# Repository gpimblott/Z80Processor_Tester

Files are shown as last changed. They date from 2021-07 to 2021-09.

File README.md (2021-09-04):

# Z80Processor_Tester
This is a simple tester PCB for Z80 processors.  I use it for testing processors taken from ZX81 and Spectrums that I am fixing... also to test processors that I buy online.

## Software

The software is written in MPLab X to be used on a PIC 16F690 microcontroller

## Hardware

The PCB is designed in KiCad and all the necessary files are provided to create your own version

# Versions and updates

## v01 : Hardware and Software

Initial version that cycles through the address lines by returning a NOP instructuction (all zeros) for every address.  The leds will cycle through a binary sequence until the ram refresh kicks in then it will skip about.  This is still enough to test the basic operation of the chip and has enabled me to verify several dead Z80's.

This is complete and I have had boards made at PCBWay using the .zip file in the releases tab and also included in the hardware/v01 directory.  THe PCB has a non-standard DC barrel jack footprint.  I was unable to find a component to match so I 'bodged' a normal jack.

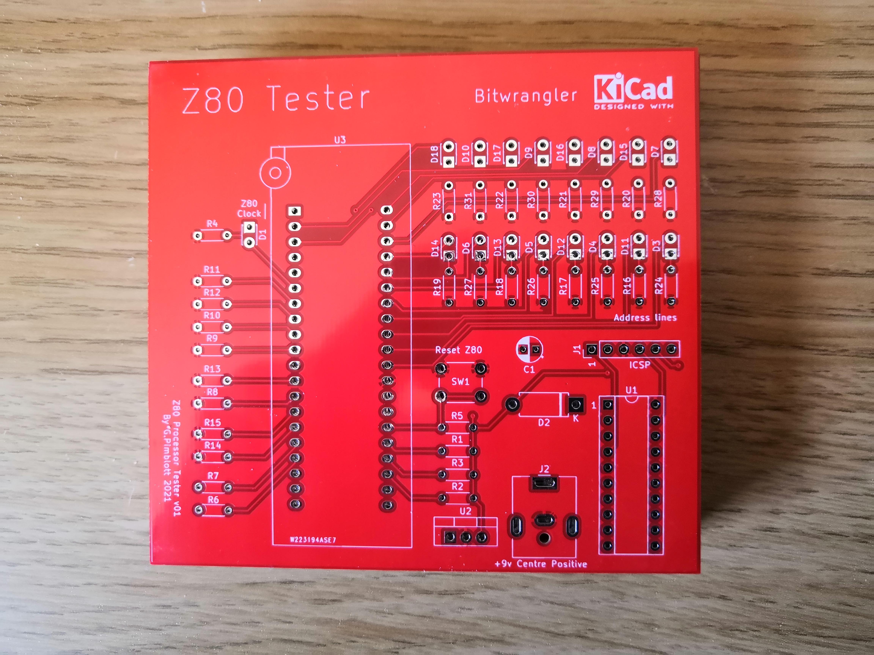
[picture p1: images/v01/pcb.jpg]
v01 PCB


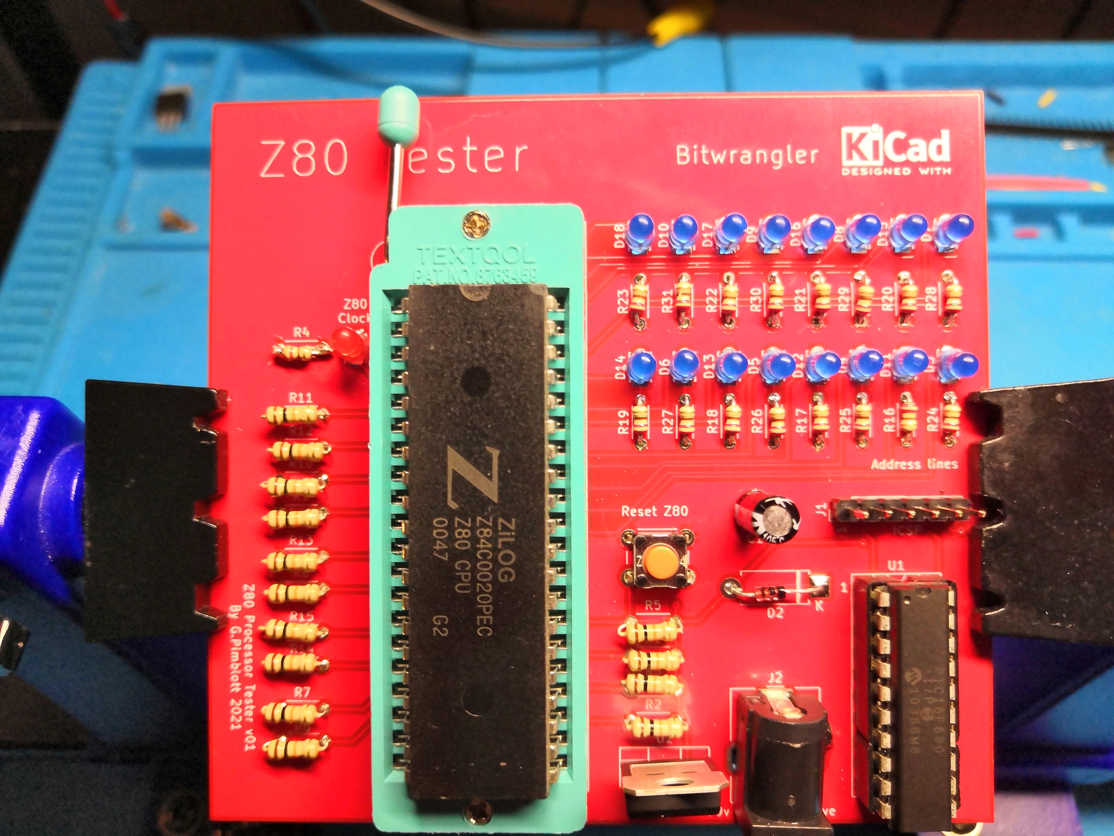
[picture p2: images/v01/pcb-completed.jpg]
v01 Completed board


## v02 : Hardware and Software - WIP

Do NOT use the hardware or software - this is WIP

This is an updated version that adds the following
* filters the DRAM refresh cycles
* Stop / Start buttons

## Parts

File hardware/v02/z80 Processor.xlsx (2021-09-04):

Component Count: | 44
Ref | Qnty | Value | Cmp name | Description
C1, | 1 | 100uf | CP | Polarized capacitor
D1, D3, D4, D5, D6, D7, D8, D9, D10, D11, D12, D13, D14, D15, D16, D17, D18, | 17 | LED | LED | Light emitting diode
D2, | 1 | 1N4148 | D_Schottky | Schottky diode
J1, | 1 | Header pins | Conn_PIC_ICSP_ICD | Microchip PIC In-Circuit Serial Programming/Debugging (ICSP/ICD) connector
J2, | 1 | Barrel_Jack | Barrel_Jack | DC Barrel Jack
R1, | 1 | 10K | R | Resistor
R4, R16, R17, R18, R19, R20, R21, R22, R23, R24, R25, R26, R27, R28, R29, R30, R31, | 17 | 150 | R | Resistor
R5, | 1 | 10k | R | Resistor
SW1, | 1 | SW_Push_Dual | SW_DPST_x2 | Single Pole Single Throw (SPST) switch, separate symbol
U1, | 1 | PIC16F690 | PIC16F690 | 4096W Flash, 256B SRAM, 256B EEPROM, DIP20
U2, | 1 | L7805 | L7805 | Positive 1.5A 35V Linear Regulator, Fixed Output 5V, TO-220/TO-263/TO-252
U3, | 1 | Z80CPU | ZIF Socket | ZIF Socket for Z80

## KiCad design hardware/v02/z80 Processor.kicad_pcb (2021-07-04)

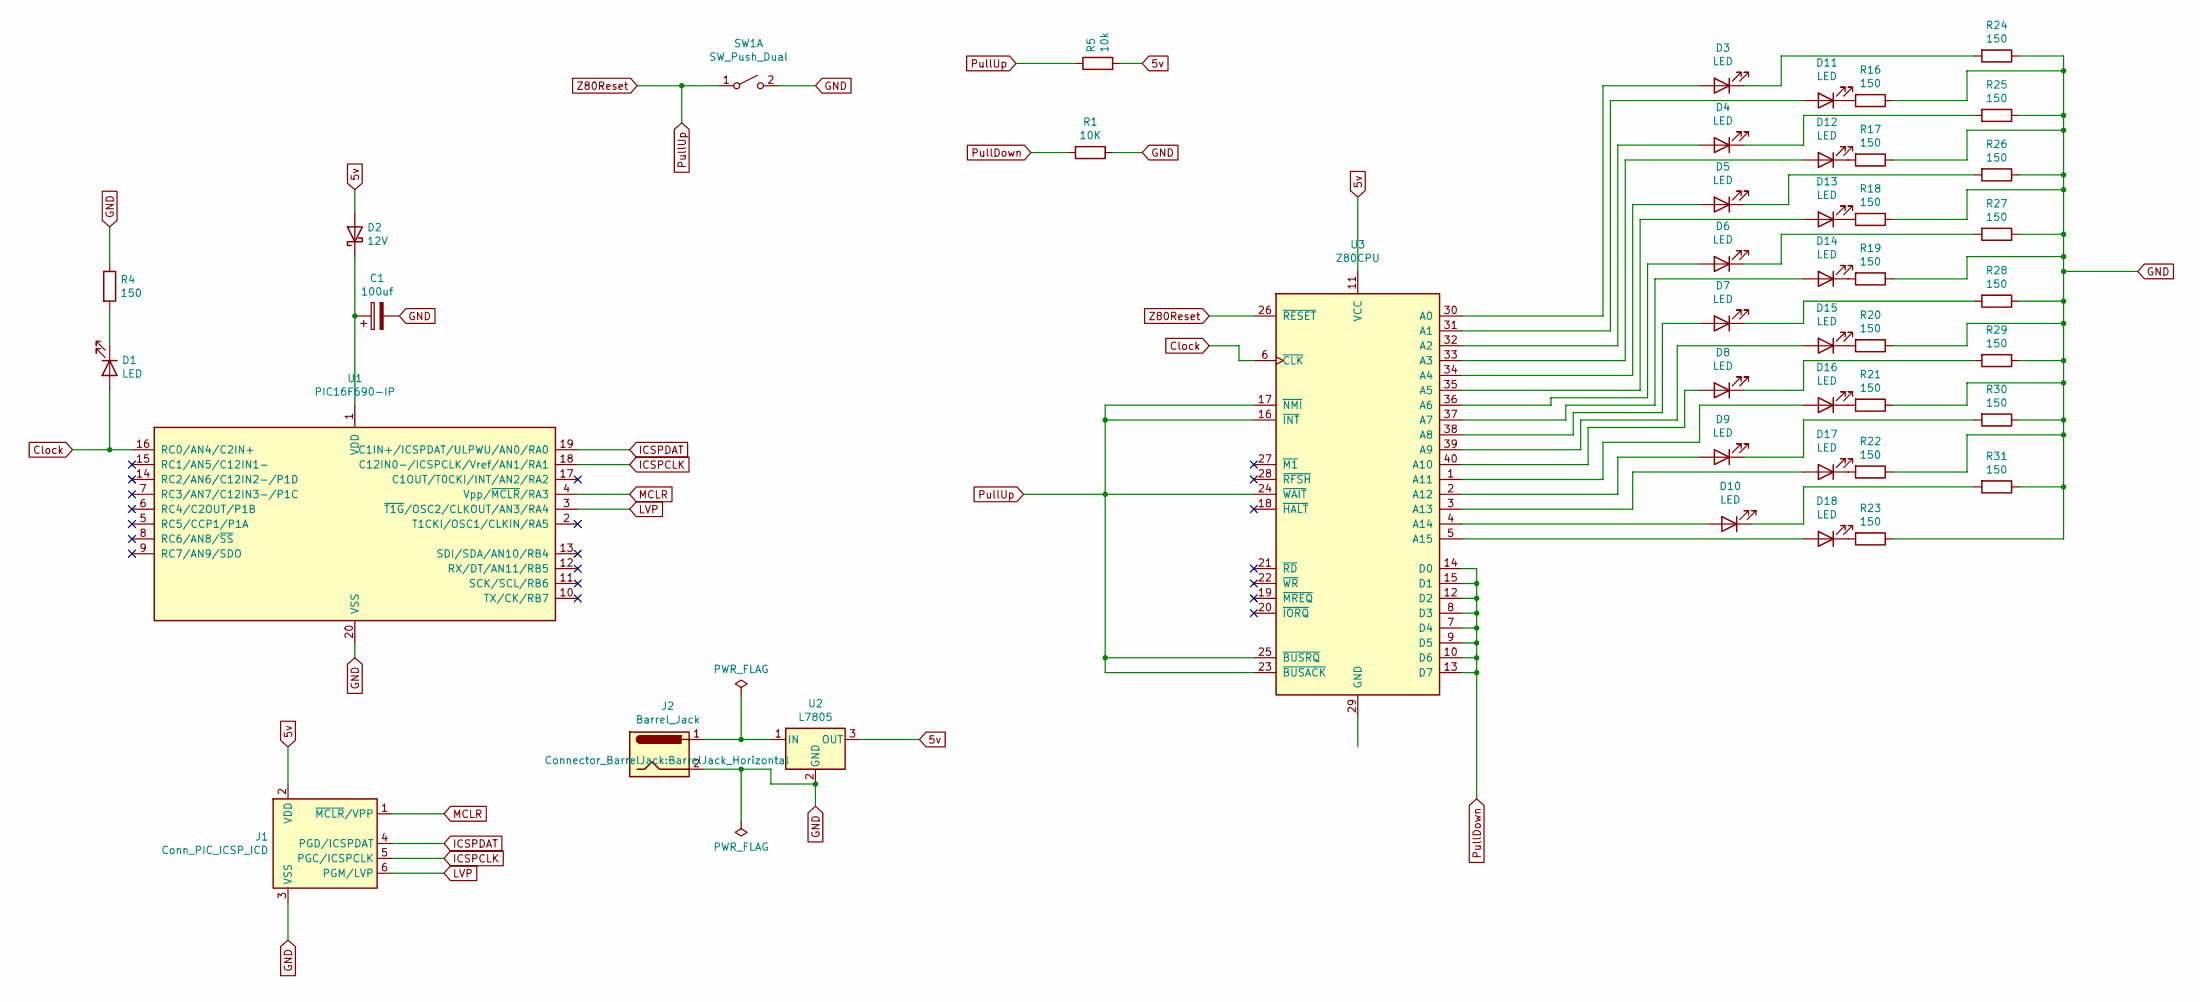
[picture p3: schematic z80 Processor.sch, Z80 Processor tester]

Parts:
C1: 100uf; CP_Radial_D4.0mm_P2.00mm
D1, D3, D4, D5, D6, D7, D8, D9, D10, D11, D12, D13, D14, D15, D16, D17, D18: LED; LED_D1.8mm_W3.3mm_H2.4mm
D2: 12V; D_DO-15_P10.16mm_Horizontal
J1: Conn_PIC_ICSP_ICD; PinHeader_1x06_P2.54mm_Vertical
J2: Barrel_Jack; BarrelJack_Horizontal
R1: 10K; R_Axial_DIN0204_L3.6mm_D1.6mm_P5.08mm_Horizontal
R4, R16, R17, R18, R19, R20, R21, R22, R23, R24, R25, R26, R27, R28, R29, R30, R31: 150; R_Axial_DIN0204_L3.6mm_D1.6mm_P5.08mm_Horizontal
R5: 10k; R_Axial_DIN0204_L3.6mm_D1.6mm_P5.08mm_Horizontal
SW1: SW_Push_Dual; SW_PUSH_6mm
U1: PIC16F690-IP; DIP-20_W7.62mm_Socket
U2: L7805; TO-220-3_Vertical
U3: Z80CPU; DIP_Socket-40_W11.9_W12.7_W15.24_W17.78_W18.5_3M_240-1280-0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

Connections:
5v: D2.2 (A), J1.2 (VDD), R5.2, U2.3 (OUT), U3.11 (VCC)
Clock: D1.2 (A), U1.16 (RC0/AN4/C2IN+), U3.6 (~CLK~)
GND: C1.2, J1.3 (VSS), J2.2, R1.1, R4.1, R16.1, R17.1, R18.1, R19.1, R20.1, R21.1, R22.1, R23.1, R24.1, R25.1, R26.1, R27.1, R28.1, R29.1, R30.1, R31.1, SW1.2 (B), U1.20 (VSS), U2.2 (GND)
ICSPCLK: J1.5 (PGC/ICSPCLK), U1.18 (C12IN0-/ICSPCLK/Vref/AN1/RA1)
ICSPDAT: J1.4 (PGD/ICSPDAT), U1.19 (C1IN+/ICSPDAT/ULPWU/AN0/RA0)
LVP: J1.6 (PGM/LVP), U1.3 (~T1G~/OSC2/CLKOUT/AN3/RA4)
MCLR: J1.1 (~MCLR~/VPP), U1.4 (Vpp/~MCLR~/RA3)
unnamed: C1.1, D2.1 (K), U1.1 (VDD)
unnamed: D1.1 (K), R4.2
unnamed: D3.1 (K), R24.2
unnamed: D3.2 (A), U3.30 (A0)
unnamed: D4.1 (K), R25.2
unnamed: D4.2 (A), U3.32 (A2)
unnamed: D5.1 (K), R26.2
unnamed: D5.2 (A), U3.34 (A4)
unnamed: D6.1 (K), R27.2
unnamed: D6.2 (A), U3.36 (A6)
unnamed: D7.1 (K), R28.2
unnamed: D7.2 (A), U3.38 (A8)
unnamed: D8.1 (K), R29.2
unnamed: D8.2 (A), U3.40 (A10)
unnamed: D9.1 (K), R30.2
unnamed: D9.2 (A), U3.2 (A12)
unnamed: D10.1 (K), R31.2
unnamed: D10.2 (A), U3.4 (A14)
unnamed: D11.1 (K), R16.2
unnamed: D11.2 (A), U3.31 (A1)
unnamed: D12.1 (K), R17.2
unnamed: D12.2 (A), U3.33 (A3)
unnamed: D13.1 (K), R18.2
unnamed: D13.2 (A), U3.35 (A5)
unnamed: D14.1 (K), R19.2
unnamed: D14.2 (A), U3.37 (A7)
unnamed: D15.1 (K), R20.2
unnamed: D15.2 (A), U3.39 (A9)
unnamed: D16.1 (K), R21.2
unnamed: D16.2 (A), U3.1 (A11)
unnamed: D17.1 (K), R22.2
unnamed: D17.2 (A), U3.3 (A13)
unnamed: D18.1 (K), R23.2
unnamed: D18.2 (A), U3.5 (A15)
unnamed: J2.1, U2.1 (IN)
PullDown: R1.2, U3.7 (D4), U3.8 (D3), U3.9 (D5), U3.10 (D6), U3.12 (D2), U3.13 (D7), U3.14 (D0), U3.15 (D1)
PullUp: R5.1, SW1.1 (A), U3.16 (~INT~), U3.17 (~NMI~), U3.23 (~BUSACK~), U3.24 (~WAIT~), U3.25 (~BUSRQ~), U3.26 (~RESET~)

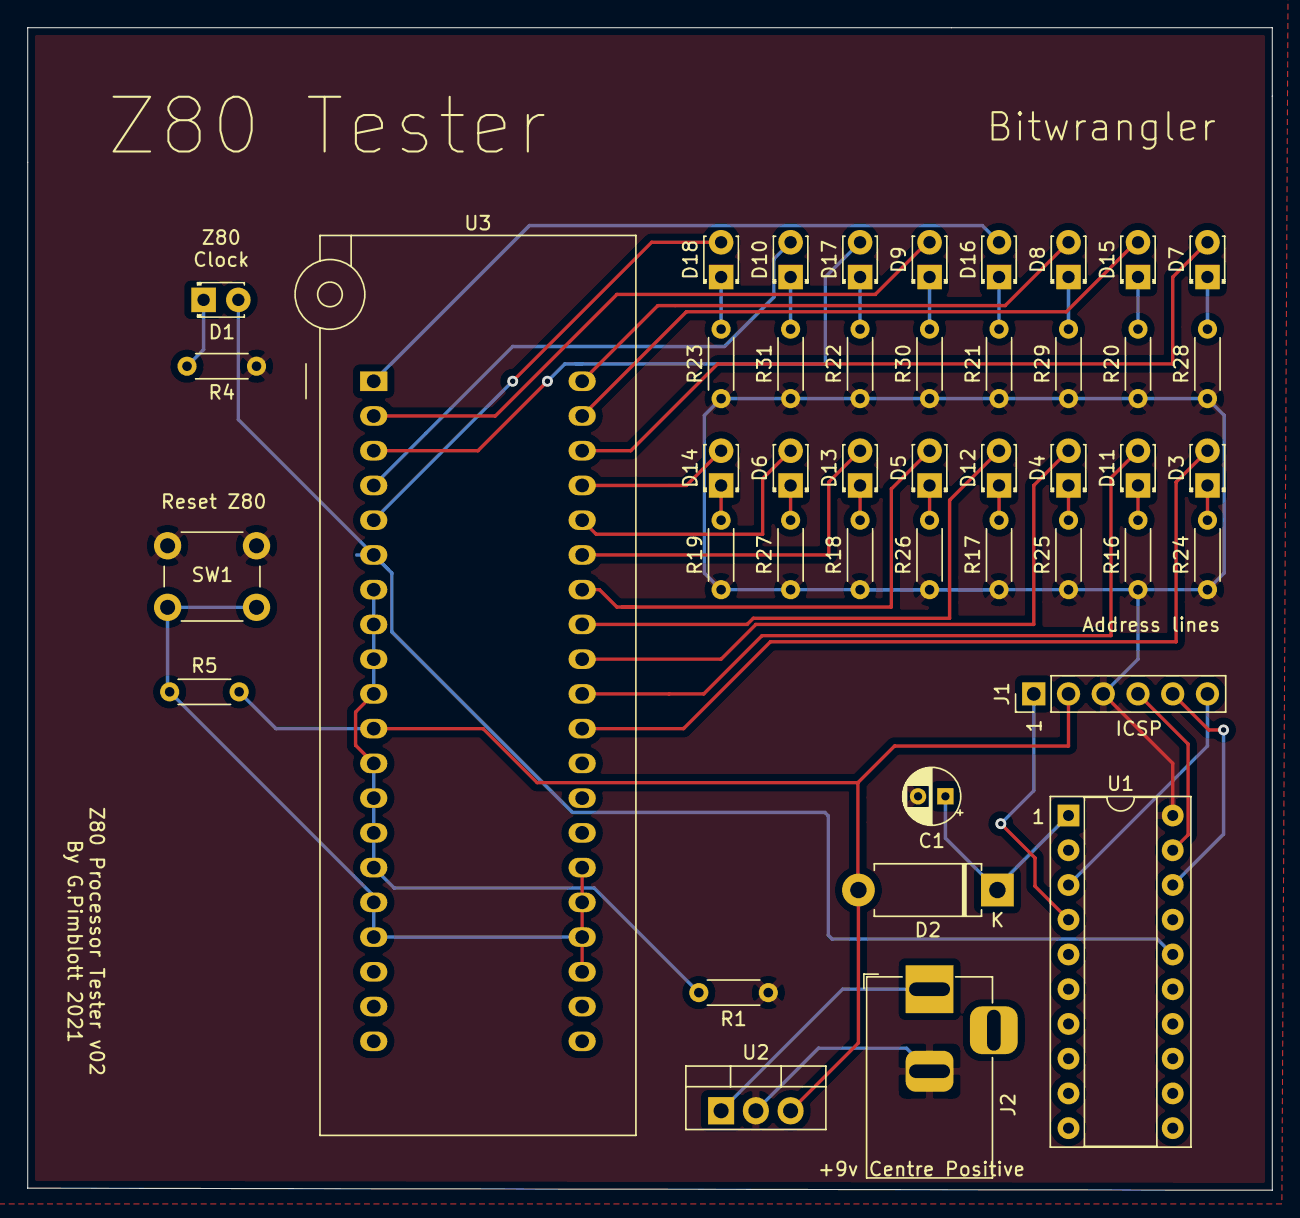
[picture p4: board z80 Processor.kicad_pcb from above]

Board: 2 copper layers, 91.0 x 85.0 mm, 44 parts (0 on the bottom side), 44 nets.

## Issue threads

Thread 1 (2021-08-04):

BOM and/or KiCad files missing

SmakyTaky, 2021-08-04:
I have been trying to reproduce your tester. Ordered some PCBs using the gerber files. However, I was unable to find the KiCad V1 files and/or a BOM to identify all the components specs

gpimblott, 2021-08-04:
The v02 Kicad files are the same at the moment so should give you the parts.  The attached image is a grab of the BOM.

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

SmakyTaky, 2021-08-04:
Thanks… this helps a lot.

What programmer should I use for this microcontroller?

Regards,

Fedro

De: G Pimblott ***@***.***>
Enviado el: Wednesday, August 4, 2021 12:48 PM
Para: gpimblott/Z80Processor_Tester ***@***.***>
CC: Fedro Ponce de León ***@***.***>; Author ***@***.***>
Asunto: Re: [gpimblott/Z80Processor_Tester] BOM and/or KiCad files missing (#1)

The v02 Kicad files are the same at the moment so should give you the parts. The attached image is a grab of the BOM.

 <https://user-images.githubusercontent.com/2563249/128229382-63f3565d-f240-42c3-8edc-e456abfc786a.png>

—
You are receiving this because you authored the thread.
Reply to this email directly, view it on GitHub <https://github.com/gpimblott/Z80Processor_Tester/issues/1#issuecomment-892850815> , or unsubscribe <https://github.com/notifications/unsubscribe-auth/ABRXE4BP24HRHIGGVICVCVTT3F4MLANCNFSM5BRMLGAQ> .
Triage notifications on the go with GitHub Mobile for iOS <https://apps.apple.com/app/apple-store/id1477376905?ct=notification-email&mt=8&pt=524675>  or Android <https://play.google.com/store/apps/details?id=com.github.android&utm_campaign=notification-email> .  <https://github.com/notifications/beacon/ABRXE4C46VQ2UVFXVIUPR3TT3F4MLA5CNFSM5BRMLGA2YY3PNVWWK3TUL52HS4DFVREXG43VMVBW63LNMVXHJKTDN5WW2ZLOORPWSZGOGU35E7Y.gif>

SmakyTaky, 2021-08-04:
I just noticed some items missing... R1-R5 (is R5 here the same value 10K as in V2)?  R7-R11. I noticed all Leds have a 150 ohm current limiting resistor.. however, besides R5, the rest are not in this BOM. I was unable to identify the values from the photos on your post.

gpimblott, 2021-08-04:
Hi, Sorry I should have paid more attention - v2 I have here is updated.

#Capacitor
C1 : 100uf

#LEDs & matching resisters
D3->D18 :  LED of your choice (I have used ultrabright blue)
D1 : Red or Green LED
R4 : Resister to match D1 (I used 150 Ohm again)
R16->R31 : Resister to match your LED I've used 150 Ohm

#Diode
D2 : 1n4148 diode

#Pulldown resisters (10K)
R1,2,3,5,6,7,8,9,10,11,12,13,14,15 : 10K resister

#PIC Chip
U1 : PIC 16F690

# 5V Regulator
U2 : 7805

# Z80
U3 : 40Pin ZIF socket

#ISCP header
J1: 6 header pins

# 9V Power Socket
J2 :  2.1 mm barrel jack - watch the pin out I had to bodge mine in as it had the wrong pins placement

To programme the PIC chip you can either use a PICKIT 2 or 3 or a TL866II Plus programmer

I have also written up the build [on my blog](https://www.bitwrangler.uk/2021/07/07/z80-processor-tester/)

SmakyTaky, 2021-08-04:
Excellent... thanks I have the TL866II Plus.. will let you know how it goes.

SmakyTaky, 2021-08-05:
One more question.. I have been looking for a compatible barrel jack.. however, I have not been able to identify one that matches the pinout of the board. Do you happen to have a part number that may be compatible?

gpimblott, 2021-08-05:
I used the wrong footprint for the barrel jack so I modded a standard one to fit the board.  I cut a leg off and snipped a corner of another :)

Closed 2021-08-04.

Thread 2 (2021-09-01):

How to Program the microcontroller

SmakyTaky, 2021-09-01:
I have a TL866II Plus programmer and found it is compatible with the microcontroller. Installed MPLAB and compilers, now I am unsure on the steps to program the microcontroller.

After building the project I noticed three files are created under production folder... Z80Tester.i, Z80Tester.p1 and Z80Tester.p1.d

Not sure if I can simply load these three files to the TL866II plus FLASH, EEPROM and CONFIG sections of the programming software. If so, which file should I load to each?

gpimblott, 2021-09-04:
Hi,  so the easiest way is to use the pre-compiled version in the repo for starters.  This is included in the repo as file '\software\v01\Z80Tester.X\dist\default\production\Z80Tester.X.production.hex'.

1) Open the Xgpro TL866II programmer tool (I'm using version 11.00)
2) Place PIC16F690 into programer
3) Set the chip to PIC16F690 @SOIC20
4) Click the 'load' button and find the .hex file above
5) Click the 'Prog' button
6) wait........... success

All done

Once you have tested in your board you should be able to change the code in MPLAB and create the necessary .hex files using the provided project.  The repo has all of the files when I run build which seems to be more than you ?

For my local version I have increased the speed of the test loop (i.e. the simulated clock speed) which makes it faster.

Hope this helps

SmakyTaky, 2021-09-04:
Thaks... It helped a lot. How do you speed up the test? On Sep 4, 2021 8:04 AM, G Pimblott ***@***.***> wrote:
Hi,  so the easiest way is to use the pre-compiled version in the repo for starters.  This is included in the repo as file '\software\v01\Z80Tester.X\dist\default\production\Z80Tester.X.production.hex'.
Open the Xgpro TL866II programmer tool (I'm using version 11.00)Place PIC16F690 into programerSet the chip to PIC16F690 @SOIC20Click the 'load' button and find the .hex file aboveClick the 'Prog' buttonwait........... success
All done
Once you have tested in your board you should be able to change the code in MPLAB and create the necessary .hex files using the provided project.  The repo has all of the files when I run build which seems to be more than you ?
For my local version I have increased the speed of the test loop (i.e. the simulated clock speed) which makes it faster.
Hope this helps

—You are receiving this because you authored the thread.Reply to this email directly, view it on GitHub, or unsubscribe.Triage notifications on the go with GitHub Mobile for iOS or Android.

gpimblott, 2021-09-04:
I have pushed a new version that reduces the wait time to 10 milliseconds between clock cycles this is much faster :) The .hex file is also also updated

SmakyTaky, 2021-09-04:
Thanks.. will update then.

De: G Pimblott ***@***.***>
Enviado el: Saturday, September 4, 2021 11:39 AM
Para: gpimblott/Z80Processor_Tester ***@***.***>
CC: Fedro Ponce de León ***@***.***>; Author ***@***.***>
Asunto: Re: [gpimblott/Z80Processor_Tester] How to Program the microcontroller (#2)

I have pushed a new version that reduces the wait time to 10 milliseconds between clock cycles this is much faster :) The .hex file is also also updated

—
You are receiving this because you authored the thread.
Reply to this email directly, view it on GitHub <https://github.com/gpimblott/Z80Processor_Tester/issues/2#issuecomment-913002393> , or unsubscribe <https://github.com/notifications/unsubscribe-auth/ABRXE4F6V6HUZUOKTPGZCRDUAJDTPANCNFSM5DHFBNKA> .
Triage notifications on the go with GitHub Mobile for iOS <https://apps.apple.com/app/apple-store/id1477376905?ct=notification-email&mt=8&pt=524675>  or Android <https://play.google.com/store/apps/details?id=com.github.android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> .   <https://github.com/notifications/beacon/ABRXE4DRXLJXESJAZ3MNZEDUAJDTPA5CNFSM5DHFBNKKYY3PNVWWK3TUL52HS4DFVREXG43VMVBW63LNMVXHJKTDN5WW2ZLOORPWSZGOGZVU7GI.gif>

Closed 2021-11-21.

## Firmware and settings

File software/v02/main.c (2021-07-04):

/* 
 * File:   main.c
 * Author: G.Pimblott
 *
 */
// CONFIG
#pragma config FOSC = INTRCIO   // Oscillator Selection bits (RC oscillator: CLKOUT function on RA4/OSC2/CLKOUT pin, RC on RA5/OSC1/CLKIN)
#pragma config WDTE = OFF       // Watchdog Timer Enable bit (WDT disabled and can be enabled by SWDTEN bit of the WDTCON register)
#pragma config PWRTE = OFF      // Power-up Timer Enable bit (PWRT disabled)
#pragma config MCLRE = ON       // MCLR Pin Function Select bit (MCLR pin function is MCLR)
#pragma config CP = OFF         // Code Protection bit (Program memory code protection is disabled)
#pragma config CPD = OFF        // Data Code Protection bit (Data memory code protection is disabled)
#pragma config BOREN = ON       // Brown-out Reset Selection bits (BOR enabled)
#pragma config IESO = ON        // Internal External Switchover bit (Internal External Switchover mode is enabled)
#pragma config FCMEN = ON       // Fail-Safe Clock Monitor Enabled bit (Fail-Safe Clock Monitor is enabled)

#define _XTAL_FREQ 8000000 // 8Mhz Crystal
//#define _XTAL_FREQ 20000000 // 20MHz crystal

#include <xc.h>

// Simple
#define ON          1
#define OFF         0

#define BTN_DOWN    0
#define BTN_UP      1

#define HIGH        1
#define LOW         0

// Define output macros
#define CLK_OUT     PORTCbits.RC0
#define INST_OUT    PORTCbits.RC1
#define RESET_OUT   PORTCbits.RC2

// Define button macros
#define STOP_START_BTN      PORTAbits.RA0
#define RESET_BTN           PORTAbits.RA1

// Constants
#define RESET_CLK_CYCLES    10


volatile unsigned char m1Count = 0;
volatile unsigned char clockRunning = OFF;
volatile unsigned char resetCount = 0;

/**
 * Setup timer 2 to generate on interrupt
 */
void init_interrupts(void) {
    // Clear the timer bits
    TMR2 = 0;
    PR2 = 0xff;

    // Set the Clock pre-scaler
    // 00 = Pre-scaler is 1
    // 01 = Pre-scaler is 4
    // 1x = Pre-scaler is 16
    T2CONbits.T2CKPS0 = 0;
    T2CONbits.T2CKPS1 = 1;

    // Set output post-scaler
    // 0000 = 1:1 Post-scaler
    // 0001 = 1:2 Post-scaler
    // 0010 = 1:3 Post-scaler
    // 0011 = 1:4 Post-scaler
    // 0100 = 1:5 Post-scaler
    // 0101 = 1:6 Post-scaler
    // 0110 = 1:7 Post-scaler
    // 0111 = 1:8 Post-scaler
    // 1000 = 1:9 Post-scaler
    // 1001 = 1:10 Post-scaler
    // 1010 = 1:11 Post-scaler
    // 1011 = 1:12 Post-scaler
    // 1100 = 1:13 Post-scaler
    // 1101 = 1:14 Post-scaler
    // 1110 = 1:15 Post-scaler
    // 1111 = 1:16 Post-scaler
    T2CONbits.TOUTPS0 = 1;
    T2CONbits.TOUTPS1 = 1;
    T2CONbits.TOUTPS2 = 1;
    T2CONbits.TOUTPS3 = 1;

    PIE1bits.TMR2IE = 1;    // Enable Timer 2 Interrupts
    T2CONbits.TMR2ON = 1;   // Turn the timer On

    /**
     * Interrupt on change
     */
//    IOCAbits.IOCA0 = 1;     //Enabled RA0 Interrupt-On-Change
//    INTCONbits.RABIE = 1;   //Enabled Interrupt-On-Change Interrupt
//    INTCONbits.RABIF = 0;   // Clear the interrupt bit
    
    /**
     * Global interrupt enable
     */
    INTCONbits.PEIE = 1;    // Enable the peripheral interrupts (which includes timer1)
    INTCONbits.GIE = 1;     // Enable global interrupts
    
    
}

/**
 * Setup timer 1 to generate an interrupt
 */
//void init_timer1(void) {
//    // Clear the timer bits
//    TMR1H = TMR1L = 0;
//
//    // Set pre-scaler to 0b10 == 4
//    // T1CKPS<1:0>: Timer1 Input Clock Pre-scale Select bits
//    // 11 = 1:8 Pre-scale Value
//    // 10 = 1:4 Pre-scale Value
//    // 01 = 1:2 Pre-scale Value
//    // 00 = 1:1 Pre-scale Value
//    T1CONbits.T1CKPS1 = 0;
//    T1CONbits.T1CKPS0 = 0;
//
//    T1CONbits.TMR1CS = 0; // Internal oscillator
//    PIE1bits.TMR1IE = 1; // Fire overflow interrupt 1
//    T1CONbits.TMR1ON = 1; // Turn the timer On
//
//    INTCONbits.PEIE = 1; // Enable the peripheral interrupts (which includes timer1)
//    INTCONbits.GIE = 1; // Enable global interrupts
//
//}

void initHW(void) {
    ANSEL = 0;          //Initialise A/D ports off
    ANSELH = 0;         //Initialise A/D ports off
    CM1CON0 = 0;        //Initialise comp 1 off
    CM2CON0 = 0;        //Initialise comp 2 off
    
    //TRISA = 0b00000100;     // RA2 as an input
    //TRISC = 0b00000000;     // All PORTC pins as outputs
    //TRISA = 0b00000111;     // A0-2 as inputs

    // Setup outputs C0 & C1
    TRISC0 = 0; // Clock signal
    TRISC1 = 0; // Instruction (M1) ?)
    TRISC2 = 0; // Reset line
    TRISC3 = 0; // Test output

    // Setup inputs
    TRISA0 = 1; // Start/Stop
    TRISA1 = 1; // Reset button
    TRISA2 = 1;

    // Set the default values

    CLK_OUT = LOW;      // Start the clock low
    INST_OUT = LOW;     // Start the instruction monitor low
    RESET_OUT = HIGH;   // Default reset line to HIGH (It's active low))
    
    //RC3 = LOW;

    init_interrupts();
}

/**
 * Interrupt handler routine
 */
__interrupt(high_priority) void myisr() {

//    if( INTCONbits.RABIF == 1 ) {
//        RC3 = HIGH;
//        
//        INTCONbits.RABIF = 0;
//    }
    
    // was interrupt was fired by timer1
    if (PIR1bits.TMR2IF == 1) {

        if (clockRunning == ON || resetCount != 0) {

            CLK_OUT = ~CLK_OUT; // Flip the clock output

            // Keep track of the instruction cycles
            if (m1Count++ == 4) {
                INST_OUT = ~INST_OUT;
                m1Count = 0;
            }

            // Check if we have finished a reset cycle
            if (resetCount > 0) {
                if (--resetCount == 0) {
                    RESET_OUT = HIGH;
                }
            }
        }

        // Re-enable timer2
        PIR1bits.TMR2IF = 0;
    }
}

/**
 * 
 */
void startReset() {
    RESET_OUT = LOW;
    resetCount = RESET_CLK_CYCLES;
}

/*
 * 
 */
int main(int argc, char** argv) {
    initHW();

    // Force a reset
    //startReset();

    // Loop forever
    while (1) {

        if (STOP_START_BTN == BTN_DOWN) {
            __delay_ms(100); // Hack to remove bounce

            // If it's on turn the clock off
            if (clockRunning == ON) {
                clockRunning = OFF;

                // Change the outputs
                CLK_OUT = 0;
                INST_OUT = 0;

                // REset counters
                m1Count = 0;
                resetCount = 0;
            } else {
                clockRunning = ON;
            }
        }

        if (RESET_BTN == BTN_DOWN) {
            __delay_ms(100); // Hack to remove bounce
            startReset();
        }
    }
    return 0;
}

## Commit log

2021-07-04 Initial push og v1 schematics
    [z80 Processor-B_Cu.gbr, z80 Processor-B_Mask.gbr, z80 Processor-B_Paste.gbr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]
2021-07-04 Standards hardware and software directory structure
    [z80 Processor.kicad_pcb, z80 Processor.sch]
2021-07-04 Added images of v01 board
2021-09-04 Update to speed of test
    [z80 Processor.xlsx]

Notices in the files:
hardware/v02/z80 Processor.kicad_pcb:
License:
